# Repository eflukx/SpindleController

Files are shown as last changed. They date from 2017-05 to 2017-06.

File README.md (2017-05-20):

# CNC Spindle Controller

Hardware and firmware for (PID) controlling universal AC motors (e.g. CNC spindles)

Device to precicely control the spindle speed of a CNC machine. I'm using a  Kress 530FM 530Watt spindle, but Anything upto 1000 Watt should probably be no problem. The design is based on https://sites.google.com/site/klaasdc/cnc-router/spindle-controller (thanks for finding a spot to mount the optical pickup Klaas!).

I've added a nice -mostly single sided- PCB and bases the design on the ubiquitous ATMega328p AVR platform. The PCB is designed to be easily built, using a mostly single sided design and through hole parts. Please be aware that the board carries lethal 230VAC mains supply. Proceed at your own risk! DisclaimerL: I take no liability whatsoever, you're on your own. Damage to spindle, fried PC, cats on fire, all your problem.!

The spindle speed is controlled by means of an optical pickup (rotational pulse) and a PID loop. A break-off mini-board with the TCRT5000 optical pickup to fit inside the Kress 530FM spindle is included in the PCB design.

## Power supply
The board includes a 6 volt mains transformer which supplies the logic power. The power supply may be omitted when the circuit is powered from the headers. Probably using the 5V out of a USB Serial (TTL!) cable will suffice to power the circuit. 

To minimize dissipation, I've chosen a 6V transformer in conjunction with a low drop linear (LDO) regulator. Alternatively you can use a standard 7805, but a slightly higher input voltage is needed. A 8-9 volt transformer will do, the heat dissipation from the 7805 will be a bit higher. Probably you'll still be ok with the ground plane as heatsink, otherwise place a small heatsink.

## Planned for 1st release
- PID controlled speed via RPM pulse.
- Manual speed control via knob (rotary encoder)
- Old school LED display
- Computer control via I2C
- Computer control via Async Serial (UART)
- Simple power control without RPM pulse (without optical pickup)

## Not in the package, for a next version maybe?
- Different display (128x64 graphic?)
- (over) Current monitoring
- Fuse 
- Coffee maker
- Dancing partygirl

This was created using KiCAD nightly (april 2017), possibly you cannot load the files in the stable version

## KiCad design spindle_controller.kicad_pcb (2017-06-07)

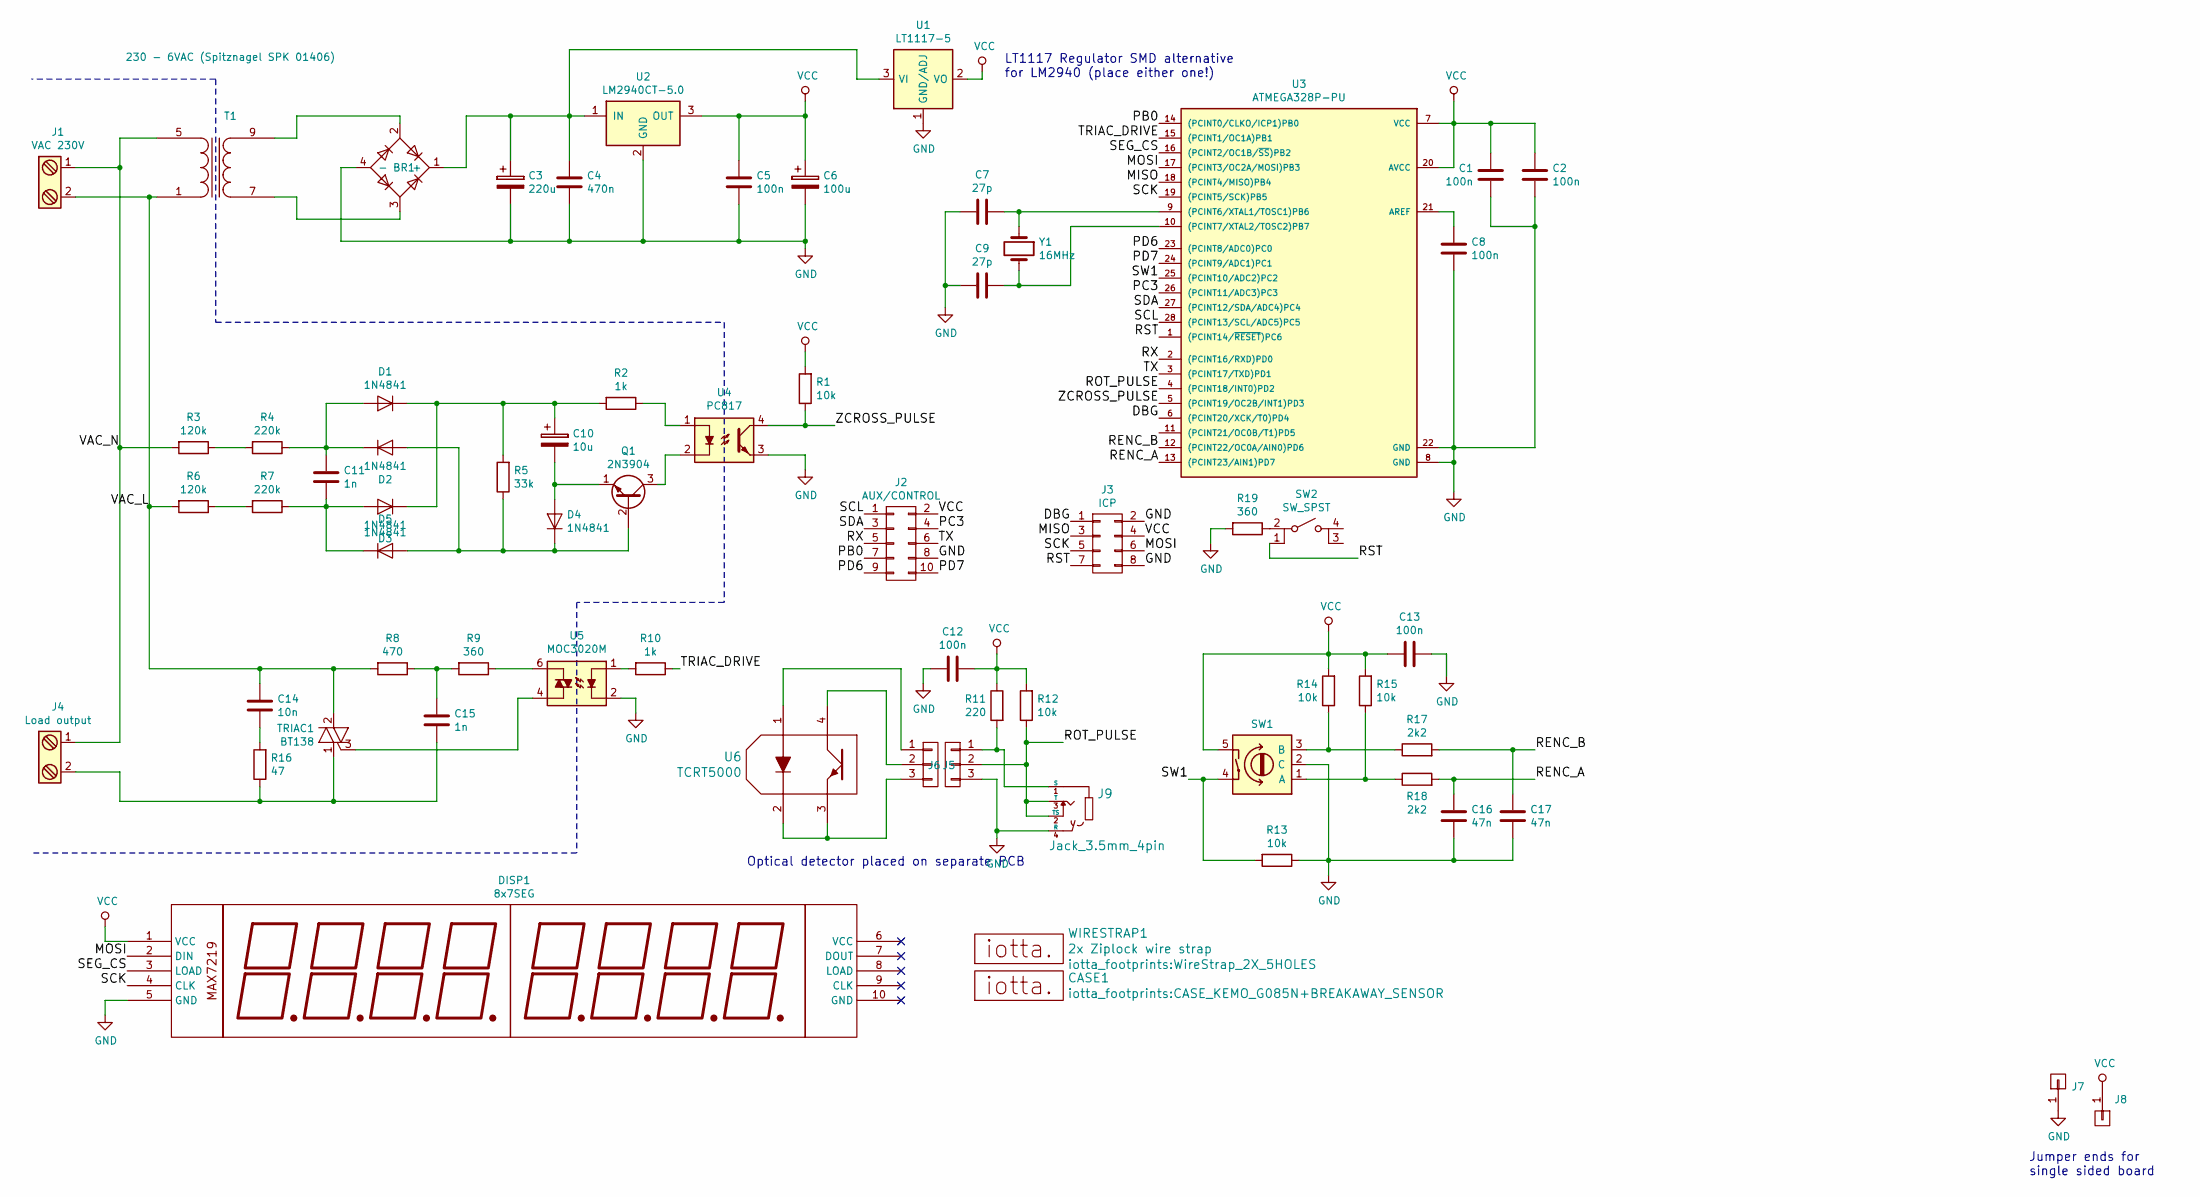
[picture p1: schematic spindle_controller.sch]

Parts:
BR1: D_Bridge_+AA-; bridge_wob
C1, C2, C5, C8, C12, C13: 100n; C_Rect_L7.0mm_W2.5mm_P5.00mm
C3: 220u; CP_Radial_D8.0mm_P3.50mm
C4: 470n; C_Rect_L7.0mm_W2.5mm_P5.00mm
C6: 100u; CP_Radial_D5.0mm_P2.00mm
C7, C9: 27p; C_Rect_L4.6mm_W2.0mm_P2.50mm_MKS02_FKP02
C10: 10u; CP_Radial_D5.0mm_P2.00mm
C11: 1n; C_Rect_L7.0mm_W2.5mm_P5.00mm
C14: 10n; C_Rect_L16.5mm_W5.0mm_P15.00mm_MKT
C15: 1n; C_Disc_D8.0mm_W5.0mm_P7.50mm
C16, C17: 47n; C_Rect_L7.0mm_W2.5mm_P5.00mm
CASE1: Case; CASE_KEMO_G085N+BREAKAWAY_SENSOR
D1, D2, D3, D4, D5: 1N4841; diode_do35
DISP1: 8x7SEG; Pin_Header_Straight_1x05_Pitch2.54mm
J1: VAC 230V; TerminalBlock_Pheonix_MKDS1.5-2pol
J2: AUX/CONTROL; Pin_Header_Angled_2x05_Pitch2.54mm
J3: ICP; Pin_Header_Angled_2x04_Pitch2.54mm
J4: Load output; TerminalBlock_Pheonix_MKDS1.5-2pol
J5, J6: CONN_01X03; Pin_Header_Angled_1x03_Pitch2.54mm
J7: GND_JUMPER; JUMPER_PIN
J8: VCC_JUMPER; JUMPER_PIN
J9: Jack_3.5mm_4pin; jack_3.5_sj1-3514-smt
Q1: 2N3904; TO-92_Molded_Narrow
R1, R12, R13, R14, R15: 10k; R_Axial_DIN0204_L3.6mm_D1.6mm_P7.62mm_Horizontal
R2, R10: 1k; R_Axial_DIN0204_L3.6mm_D1.6mm_P7.62mm_Horizontal
R3, R6: 120k; R_Axial_DIN0204_L3.6mm_D1.6mm_P7.62mm_Horizontal
R4, R7: 220k; R_Axial_DIN0204_L3.6mm_D1.6mm_P7.62mm_Horizontal
R5: 33k; R_Axial_DIN0204_L3.6mm_D1.6mm_P7.62mm_Horizontal
R8: 470; R_Axial_DIN0204_L3.6mm_D1.6mm_P7.62mm_Horizontal
R9, R19: 360; R_Axial_DIN0204_L3.6mm_D1.6mm_P7.62mm_Horizontal
R11: 220; R_Axial_DIN0204_L3.6mm_D1.6mm_P7.62mm_Horizontal
R16: 47; R_Axial_DIN0414_L11.9mm_D4.5mm_P15.24mm_Horizontal
R17, R18: 2k2; R_Axial_DIN0204_L3.6mm_D1.6mm_P7.62mm_Horizontal
SW1: Rotary_Encoder_Switch; encoder_alps-ec12d
SW2: SW_SPST; SW_PUSH_6mm
T1: 230 - 6VAC (Spitznagel SPK 01406); Trafo_CHK-EI30-2VA_1xSec
TRIAC1: BT138; TO-220_Vertical
U1: LT1117-5; SOT-223
U2: LM2940CT-5.0; TO-220_Horizontal_connected_tab
U3: ATMEGA328P-PU; DIP-28_W7.62mm
U4: PC817; DIP-4_W7.62mm
U5: MOC3020M; DIP-6_W7.62mm
U6: TCRT5000
WIRESTRAP1: 2x Ziplock wire strap; WireStrap_2X_5HOLES
Y1: 16MHz; Crystal_HC49-U_Vertical

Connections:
/DBG: J3.1, U3.6 ((PCINT20/XCK/T0)PD4)
/MISO: J3.3, U3.18 ((PCINT4/MISO)PB4)
/MOSI: DISP1.2 (DIN), J3.6, U3.17 ((PCINT3/OC2A/MOSI)PB3)
/PB0: J2.7, U3.14 ((PCINT0/CLKO/ICP1)PB0)
/PC3: J2.4, U3.26 ((PCINT11/ADC3)PC3)
/PD6: J2.9, U3.23 ((PCINT8/ADC0)PC0)
/PD7: J2.10, U3.24 ((PCINT9/ADC1)PC1)
/RENC_A: C16.2, R18.2, U3.13 ((PCINT23/AIN1)PD7)
/RENC_B: C17.2, R17.2, U3.12 ((PCINT22/OC0A/AIN0)PD6)
/ROT_PULSE: J6.2, J9.2 (TS), J9.3 (T), R12.1, U3.4 ((PCINT18/INT0)PD2)
/RST: J3.7, SW2.1, U3.1 ((PCINT14/~RESET~)PC6)
/RX: J2.5, U3.2 ((PCINT16/RXD)PD0)
/SCK: DISP1.4 (CLK), J3.5, U3.19 ((PCINT5/SCK)PB5)
/SCL: J2.1, U3.28 ((PCINT13/SCL/ADC5)PC5)
/SDA: J2.3, U3.27 ((PCINT12/SDA/ADC4)PC4)
/SEG_CS: DISP1.3 (LOAD), U3.16 ((PCINT2/OC1B/~SS~)PB2)
/SW1: R13.2, SW1.4, U3.25 ((PCINT10/ADC2)PC2)
/TRIAC_DRIVE: R10.1, U3.15 ((PCINT1/OC1A)PB1)
/TX: J2.6, U3.3 ((PCINT17/TXD)PD1)
/VAC_L: C14.1, J1.2, R6.2, R8.2, T1.1 (AA), TRIAC1.2 (A1)
/VAC_N: J1.1, J4.1, R3.2, T1.5 (AB)
/ZCROSS_PULSE: R1.1, U3.5 ((PCINT19/OC2B/INT1)PD3), U4.4
GND: BR1.4 (-), C1.2, C2.1, C3.2, C4.2, C5.2, C6.2, C7.2, C8.2, C9.2, C12.2, C13.1, C16.1, C17.1, DISP1.5 (GND), J2.8, J3.2, J3.8, J6.3, J7.1, J9.4 (R), R13.1, R19.2, SW1.2 (C), U1.1 (GND/ADJ), U2.2 (GND), U3.8 (GND), U3.22 (GND), U4.3, U5.2; also elsewhere on the board
unnamed: BR1.1 (+), C3.1, C4.1, U1.3 (VI), U2.1 (IN)
unnamed: BR1.2, T1.9 (SA)
unnamed: BR1.3, T1.7 (SB)
unnamed: C7.1, U3.9 ((PCINT6/XTAL1/TOSC1)PB6), Y1.1
unnamed: C8.1, U3.21 (AREF)
unnamed: C9.1, U3.10 ((PCINT7/XTAL2/TOSC2)PB7), Y1.2
unnamed: C10.1, D1.1 (K), D3.1 (K), R2.2, R5.2
unnamed: C10.2, D4.2 (A), Q1.1 (E)
unnamed: C11.1, D1.2 (A), D2.1 (K), R4.1
unnamed: C11.2, D3.2 (A), D5.1 (K), R7.1
unnamed: C14.2, R16.2
unnamed: C15.1, R8.1, R9.2
unnamed: C15.2, J4.2, R16.1, TRIAC1.1 (A2)
unnamed: D2.2 (A), D4.1 (K), D5.2 (A), Q1.2 (B), R5.1
unnamed: J5.1, U6.1
unnamed: J5.2, U6.4
unnamed: J5.3, U6.2, U6.3
unnamed: J6.1, J9.1 (S), R11.2
unnamed: Q1.3 (C), U4.2
unnamed: R2.1, U4.1
unnamed: R3.1, R4.2
unnamed: R6.1, R7.2
unnamed: R9.1, U5.6
unnamed: R10.2, U5.1
unnamed: R14.1, R17.1, SW1.3 (B)
unnamed: R15.1, R18.1, SW1.1 (A)
unnamed: R19.1, SW2.2
unnamed: TRIAC1.3 (G), U5.4
VCC: C1.1, C2.2, C5.1, C6.1, C12.1, C13.2, DISP1.1 (VCC), J2.2, J3.4, J8.1, R1.2, R11.1, R12.2, R14.2, R15.2, SW1.5, U1.2 (VO), U1.4 (VO), U2.3 (OUT), U3.7 (VCC), U3.20 (AVCC); also elsewhere on the board

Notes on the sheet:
Optical detector placed on separate PCB
LT1117 Regulator SMD alternative for LM2940 (place either one!)
Jumper ends for single sided board

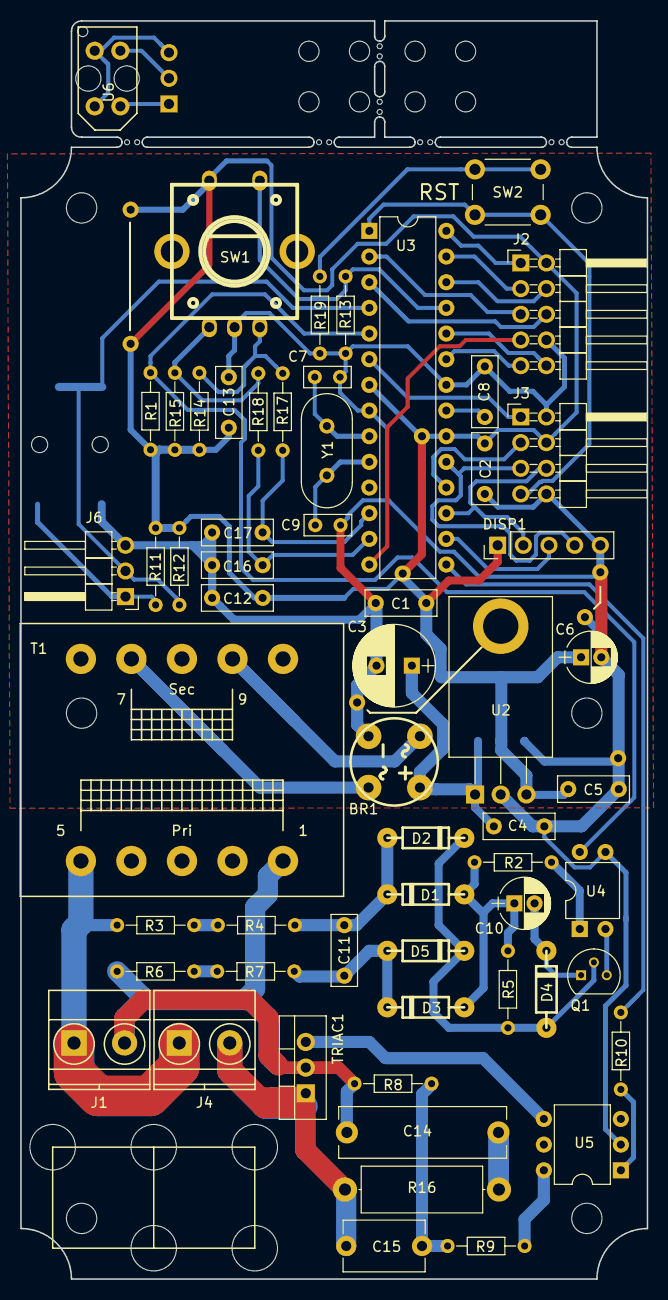
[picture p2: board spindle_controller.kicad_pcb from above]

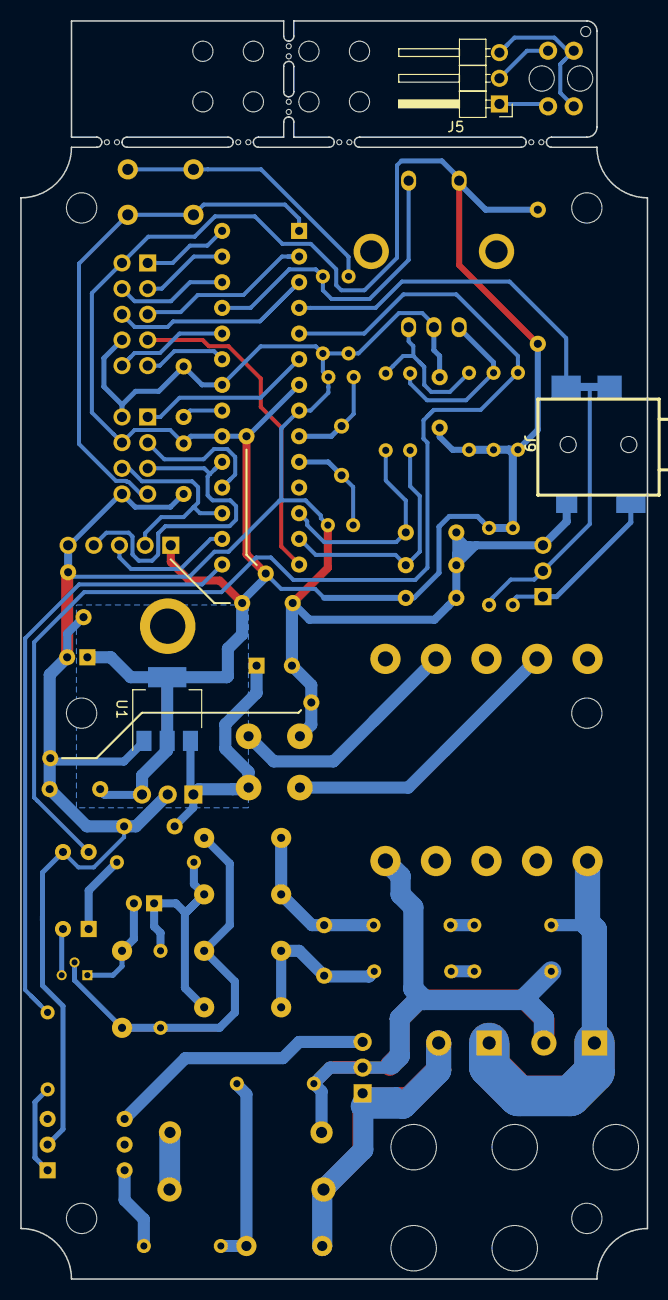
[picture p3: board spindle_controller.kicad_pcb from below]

Board: 2 copper layers, 62.0 x 124.5 mm, 72 parts (3 on the bottom side), 52 nets.

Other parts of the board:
J7#2, J7#3, J7#4: GND_JUMPER; JUMPER_PIN
J8#2, J8#3, J8#4: VCC_JUMPER; JUMPER_PIN

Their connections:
GND: J7#2.1, J7#3.1, J7#4.1; also elsewhere on the board
VCC: J8#2.1, J8#3.1, J8#4.1; also elsewhere on the board

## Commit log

2017-04-14 Add schematic and footprints
    [spindle_controller.kicad_pcb, spindle_controller.sch]
2017-04-14 Add board routing halfway
    [spindle_controller.kicad_pcb, spindle_controller.sch]
2017-04-15 Add shuffled AC cord entry, ziplock holes, 1117 regulator alternative, shuffled linear supply
    [spindle_controller.kicad_pcb, spindle_controller.sch]
2017-04-15 Finish routing. Need to draw break-off slots.
    [spindle_controller.kicad_pcb, spindle_controller.sch]
2017-04-16 Add jumper wires for single sided PCB's
    [spindle_controller.kicad_pcb, spindle_controller.sch]
2017-04-16 Add breakaway board for optical sensor, general board updates, dissipation planes, screw clearances and silkscreen
    [spindle_controller.kicad_pcb, spindle_controller.sch]
2017-05-18 Rearranged pin ouputs (PB0 and PC3 now separate), added rotary debounce (not on PCB yet), added 3mm jack for optical pickup
    [spindle_controller.kicad_pcb, spindle_controller.sch]
2017-05-20 Add debounce RC network on rotary encoder, improved single sided routing. Higher clearances where possible better result when milling (routing :)) the board.
    [spindle_controller.kicad_pcb]
2017-05-30 Small updates to VCC plane at 1117 regulator.
    [spindle_controller.kicad_pcb]
2017-06-07 Place value fields on PCB
    [spindle_controller.kicad_pcb]
2017-06-07 Add reset button
    [spindle_controller.kicad_pcb, spindle_controller.sch]
